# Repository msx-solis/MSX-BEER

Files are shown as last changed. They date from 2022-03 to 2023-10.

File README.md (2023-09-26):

# MSX-BEER
The MSX-Beer202 is a simple IDE interface for the MSX computers that not require to have more than 64K to use a hard disk. Original design by Solid and improved by some others (Yeti, FabF,...) in their own versions.

MSXmakers version 1.1 on "beer_ide_kicad" and "gerber" folders.
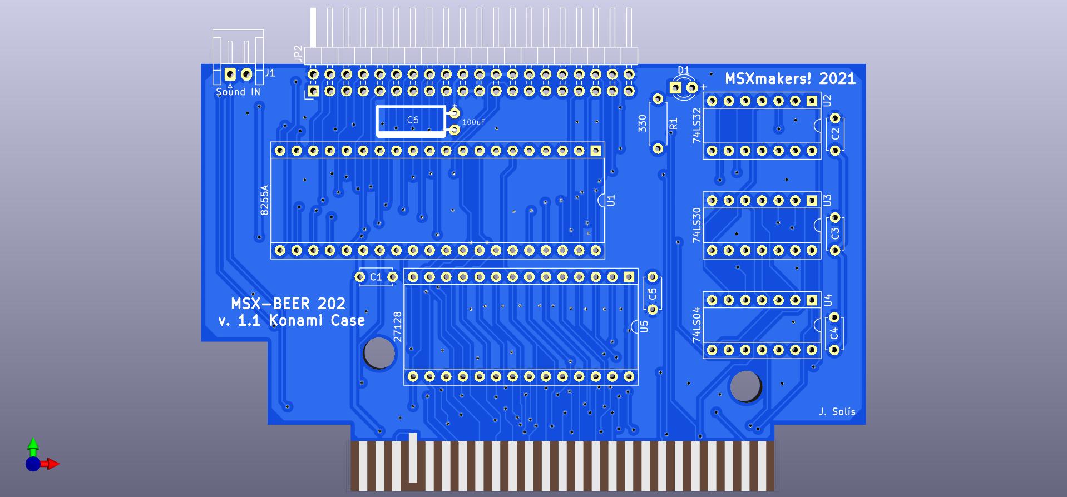
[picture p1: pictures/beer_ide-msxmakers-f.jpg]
card

More info:

Links for ide-beer202:

Here you have very good instructions (in portuguesse). Talk about the problems with some 82c55 versions and how to format with "SD fortater".
(Full overWrite y size adjustament = on).

http://basshp.blogspot.com/2014/04/beer-202-ata-ide-review.html

Here you have a demostration video for this distribution: https://www.youtube.com/watch?v=AeNEiQcKNEI&t=1s

And here you have lots of BEER interface details

https://www.pjrc.com/tech/8051/ide/wesley.html

Some more links

https://www.msx.org/wiki/Beer_202

https://hansotten.file-hunter.com/do-it-yourself/beer-ide/

https://www.pjrc.com/tech/8051/ide/wesley.html

https://www.msx.org/es/news/software/es/beer-202-ide-interface-utilidad-de-particionado

https://www.msx.org/forum/msx-talk/hardware/beer-202-ide-interface?page=2

http://www.retrocomputacion.com/forum/hardware_msx/4440/experimentos-con-la-beer-interface-ide-para-msx-1-y-2/&p=2

Some files:

https://msx.org/forum/msx-talk/hardware/beer-ide-bios-19rc1-source-code-wanted?page=1

https://sysadminmosaic.ru/en/msx/beer_ide/beer_ide

Discussion about the version SD and some more files:

http://www.nedopc.org/forum/viewtopic.php?f=96&t=18820&sid=d75385e94fd1d6dbab35a1f73d379176&start=45#p144050

Another software to clone RAW disks called HDD Raw Copy Rool v1.10 (for windows):

http://www.hddguru.com/

Another system menu for game loading.

https://www.msxall.com/download/msxmenu-v1.68-beer.zip

And here you have a demostration video for this ditribution: https://www.youtube.com/watch?v=a2agPfgZmI0&t=596s

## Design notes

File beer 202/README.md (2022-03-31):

BEER IDE 202 PACK

CONTENTS

SD FORMATER (UTILITY TO PREPARE THE OP CARD/ BE FORMATTED).
BEER IDE FORMATER (BEER FORMATTER FOR WINDOWS)
FIRMWARE 1.9 (FIRMWARE COMPATIBLE WITH COMPACT FLASH)
SCHEMATICS (ELECTRONIC SCHEME)

MORE INFORMATION:

http://www.basshp.msxall.com
http://www.basshp.blogspot.com

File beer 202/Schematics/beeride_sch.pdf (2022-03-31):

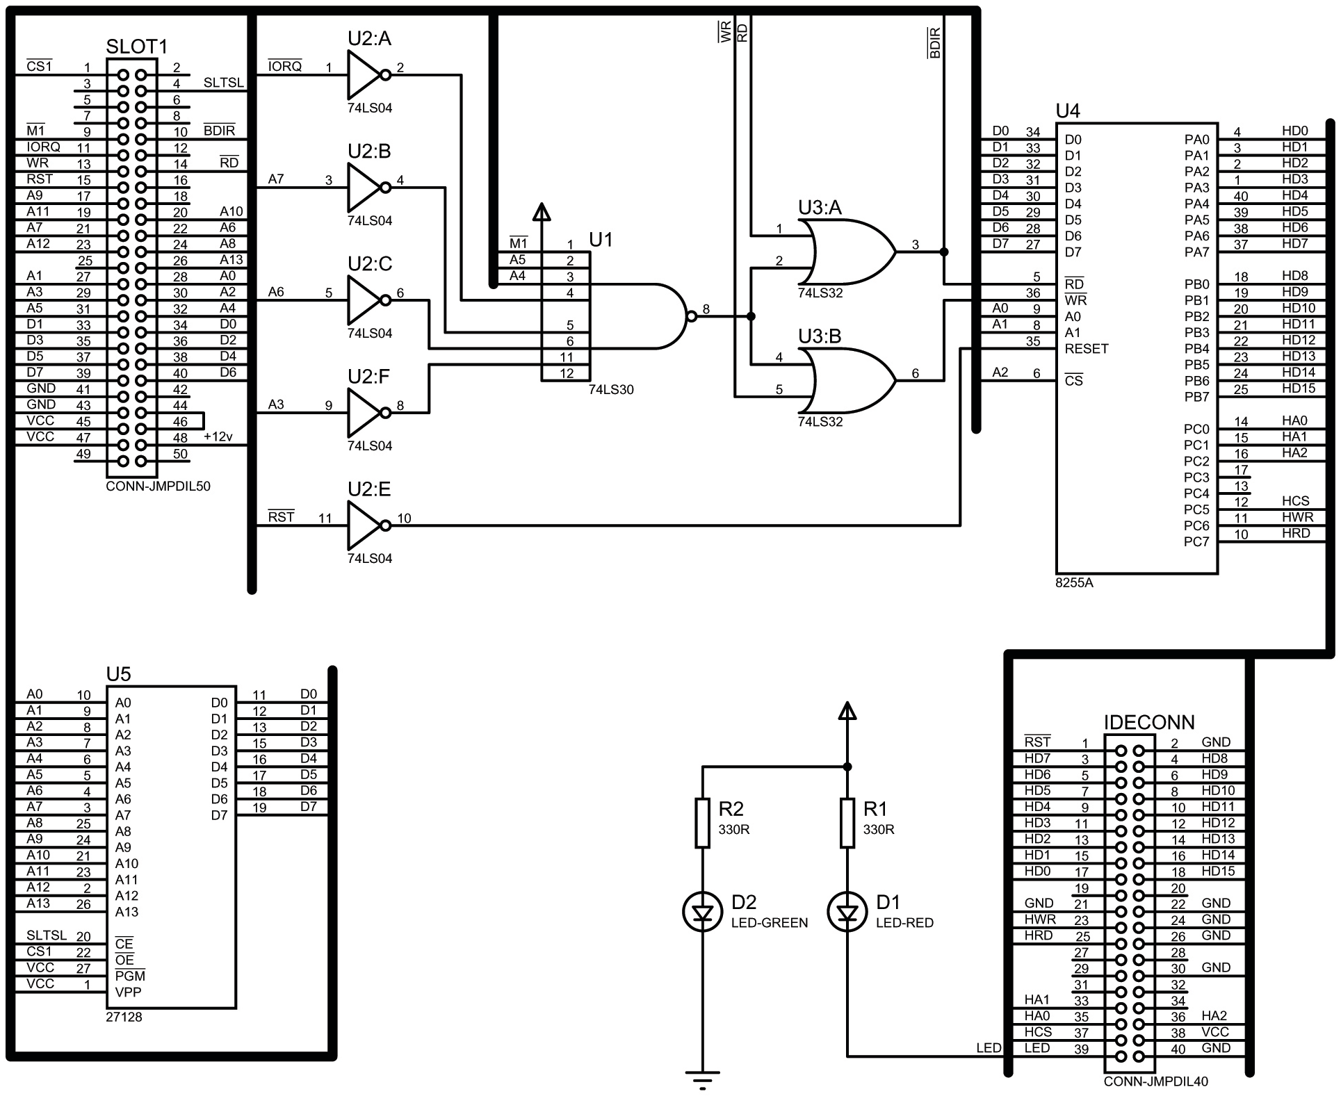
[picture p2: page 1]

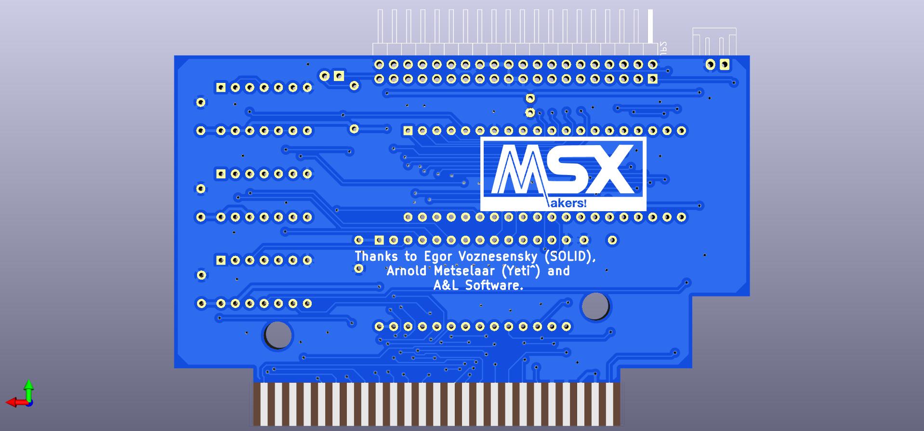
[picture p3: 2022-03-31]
pictures/beer_ide-msxmakers-b.jpg

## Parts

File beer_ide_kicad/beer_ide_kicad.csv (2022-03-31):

Reference | Value | Footprint | Datasheet
U4 | 74LS04 | Package_DIP:DIP-14_W7.62mm_Socket | http://www.ti.com/lit/gpn/sn74LS04
U3 | 74LS30 | Package_DIP:DIP-14_W7.62mm_Socket | http://www.ti.com/lit/gpn/sn74LS30
U2 | 74LS32 | Package_DIP:DIP-14_W7.62mm_Socket | http://www.ti.com/lit/gpn/sn74LS32
U1 | 8255A | Package_DIP:DIP-40_W15.24mm_Socket | http://aturing.umcs.maine.edu/~meadow/courses/cos335/Intel8255A.pdf
U5 | 27128 | Package_DIP:DIP-28_W15.24mm_Socket | http://eeshop.unl.edu/pdf/27128.pdf
JP2 | PINHD-02x20 | Connector_PinHeader_2.54mm:PinHeader_2x20_P2.54mm_Horizontal | ~
CN1 | MSX_SLOT_CON | MSXmakers2:CARTRIDGE_#_MSX_XL
D1 | LED | LED_THT:LED_D3.0mm | ~
C1 | 100nF | Capacitor_THT:C_Disc_D4.7mm_W2.5mm_P5.00mm | ~
C2 | 100nF | Capacitor_THT:C_Disc_D4.7mm_W2.5mm_P5.00mm | ~
C3 | 100nF | Capacitor_THT:C_Disc_D4.7mm_W2.5mm_P5.00mm | ~
C4 | 100nF | Capacitor_THT:C_Disc_D4.7mm_W2.5mm_P5.00mm | ~
C5 | 100nF | Capacitor_THT:C_Disc_D4.7mm_W2.5mm_P5.00mm | ~
C6 | 100uF | MSXmakers2:CP_tumbado | ~
J1 | Sound IN | Connector_JST:JST_EH_S2B-EH_1x02_P2.50mm_Horizontal | ~

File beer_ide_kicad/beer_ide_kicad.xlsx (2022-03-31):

Reference | Value | Footprint | Datasheet | QTY
C1-C5 | 100nF | C_Disc_D4.7mm_W2.5mm_P5.00mm | ~ | 5
C6 | Electrolithic cap 100uF / 16v | MSXmakers2:CP_tumbado | ~ | 1
PCB | MSX-BEER PCB | CARTRIDGE_#_MSX_XL |  | 1
D1 | LED 3mm | LED_D3.0mm | ~ | 1
J1 | 1x02 JST connector 90 degrees | JST_EH_S2B-EH_1x02_P2.50mm_Horizontal | ~ | 1
JP2 | PIN Header 02x20 shrouded | PinHeader_2x20_P2.54mm_Horizontal | ~ | 1
U1 | 82C55A | DIP-40_W15.24mm_Socket | http://aturing.umcs.maine.edu/~meadow/courses/cos335/Intel8255A.pdf | 1
U2 | 74LS32 | DIP-14_W7.62mm_Socket | http://www.ti.com/lit/gpn/sn74LS32 | 1
U3 | 74LS30 | DIP-14_W7.62mm_Socket | http://www.ti.com/lit/gpn/sn74LS30 | 1
U4 | 74LS04 | DIP-14_W7.62mm_Socket | http://www.ti.com/lit/gpn/sn74LS04 | 1
U5 | 27C128 | DIP-28_W15.24mm_Socket | http://eeshop.unl.edu/pdf/27128.pdf | 1
R1 | 330ohms | resistencia through hole |  | 1
Z1 | zócalo 40dip600 | 40DIP600 |  | 1
Z5 | zócalo 28dip600 | 28DIP600 |  | 1
Z2-4 | zócalo 14dip300 | 14DIP300 |  | 3

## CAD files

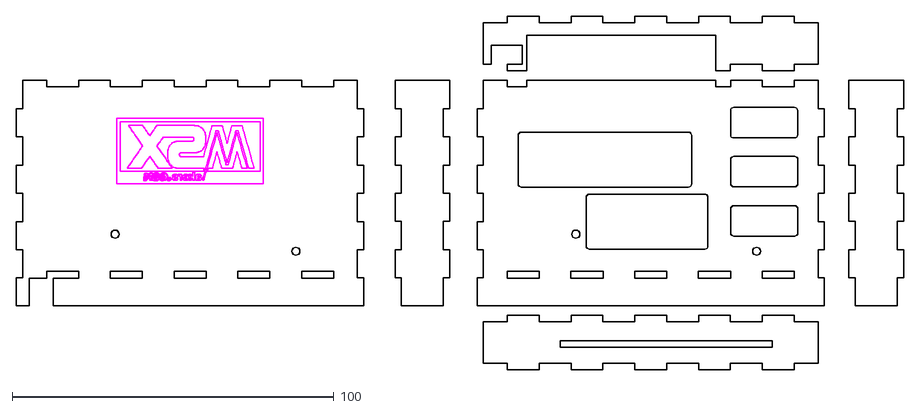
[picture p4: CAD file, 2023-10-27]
case/BEER_machimbrado_0.02mm_new_logo_R12.dxf
275.8 x 110.0

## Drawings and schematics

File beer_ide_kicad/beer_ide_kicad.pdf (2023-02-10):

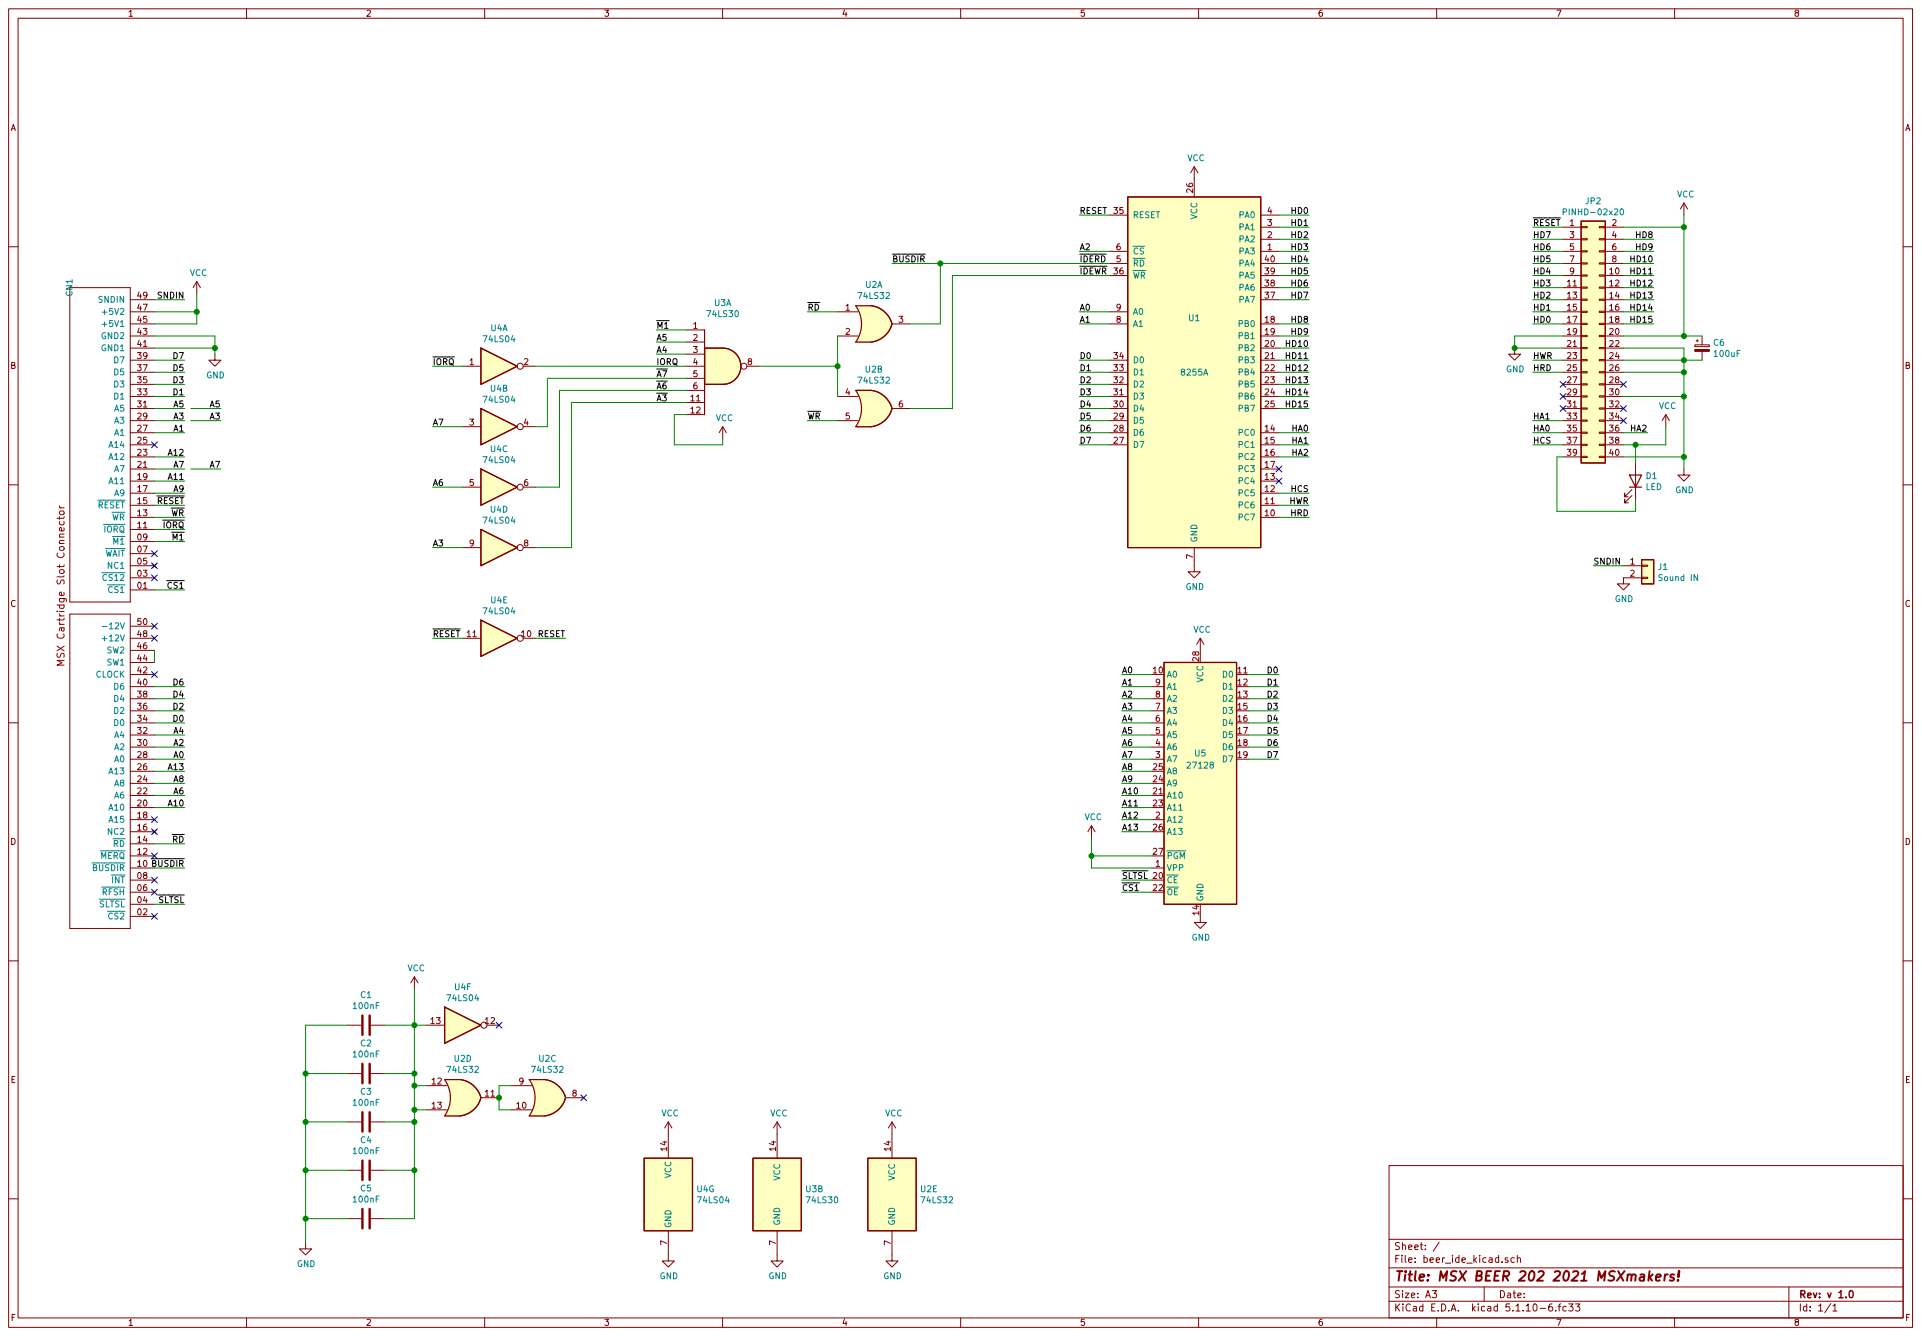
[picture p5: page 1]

File: beer_ide_kicad.sch Sheet: /
Id: 1/1 Title: MSX BEER 202 2021 MSXmakers!

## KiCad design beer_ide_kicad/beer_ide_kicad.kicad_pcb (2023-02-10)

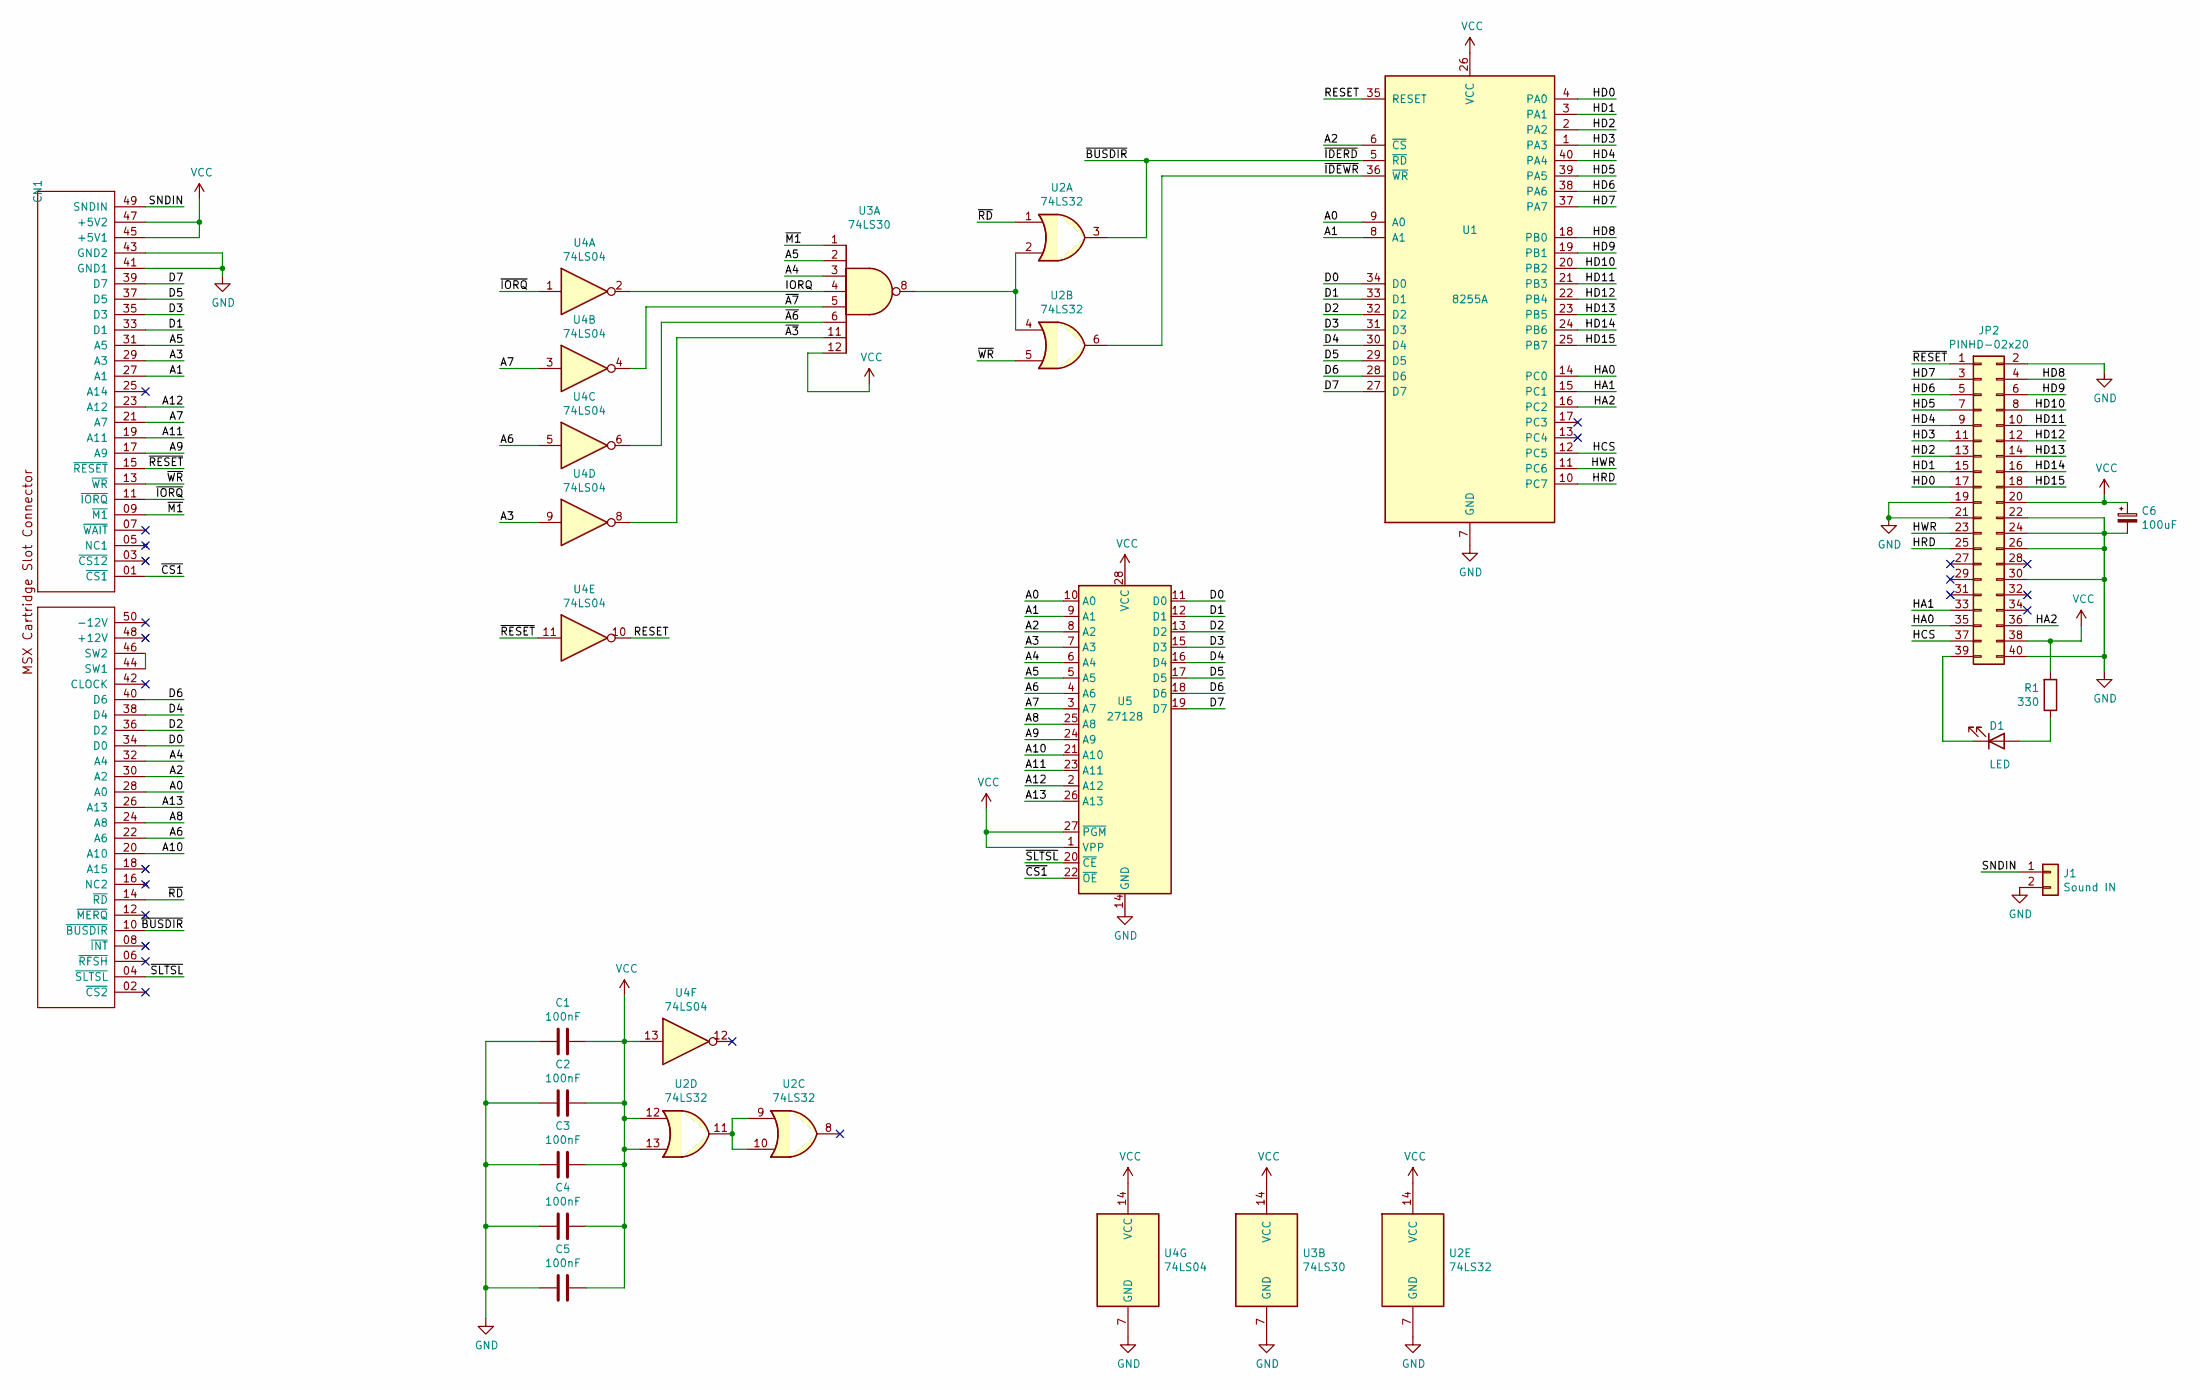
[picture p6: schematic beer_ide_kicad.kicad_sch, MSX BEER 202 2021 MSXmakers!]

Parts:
C1, C2, C3, C4, C5: 100nF; C_Disc_D4.7mm_W2.5mm_P5.00mm
C6: 100uF; CP_tumbado
CN1: MSX_SLOT_CON; CARTRIDGE_#_MSX_XL
D1: LED; LED_D3.0mm
J1: Sound IN; JST_EH_S2B-EH_1x02_P2.50mm_Horizontal
JP2: PINHD-02x20; PinHeader_2x20_P2.54mm_Horizontal
R1: 330; R_Axial_DIN0207_L6.3mm_D2.5mm_P7.62mm_Horizontal
U1: 8255A; DIP-40c_W15.24mm_LongPads
U2: 74LS32; DIP-14_W7.62mm_LongPads_0.9
U3: 74LS30; DIP-14c_W7.62mm_LongPads
U4: 74LS04; DIP-14c_W7.62mm_LongPads
U5: 27128; DIP-28c_W15.24mm_Socket_LongPads

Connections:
/A0: CN1.28 (A0), U1.9 (A0), U5.10 (A0)
/A1: CN1.27 (A1), U1.8 (A1), U5.9 (A1)
/A2: CN1.30 (A2), U1.6 (~CS), U5.8 (A2)
/A3: CN1.29 (A3), U4.9, U5.7 (A3)
/A4: CN1.32 (A4), U3.3, U5.6 (A4)
/A5: CN1.31 (A5), U3.2, U5.5 (A5)
/A6: CN1.22 (A6), U4.5, U5.4 (A6)
/A7: CN1.21 (A7), U4.3, U5.3 (A7)
/A8: CN1.24 (A8), U5.25 (A8)
/A9: CN1.17 (A9), U5.24 (A9)
/A10: CN1.20 (A10), U5.21 (A10)
/A11: CN1.19 (A11), U5.23 (A11)
/A12: CN1.23 (A12), U5.2 (A12)
/A13: CN1.26 (A13), U5.26 (A13)
/D0: CN1.34 (D0), U1.34 (D0), U5.11 (D0)
/D1: CN1.33 (D1), U1.33 (D1), U5.12 (D1)
/D2: CN1.36 (D2), U1.32 (D2), U5.13 (D2)
/D3: CN1.35 (D3), U1.31 (D3), U5.15 (D3)
/D4: CN1.38 (D4), U1.30 (D4), U5.16 (D4)
/D5: CN1.37 (D5), U1.29 (D5), U5.17 (D5)
/D6: CN1.40 (D6), U1.28 (D6), U5.18 (D6)
/D7: CN1.39 (D7), U1.27 (D7), U5.19 (D7)
/HA0: JP2.35, U1.14 (PC0)
/HA1: JP2.33, U1.15 (PC1)
/HA2: JP2.36, U1.16 (PC2)
/HCS: JP2.37, U1.12 (PC5)
/HD0: JP2.17, U1.4 (PA0)
/HD1: JP2.15, U1.3 (PA1)
/HD2: JP2.13, U1.2 (PA2)
/HD3: JP2.11, U1.1 (PA3)
/HD4: JP2.9, U1.40 (PA4)
/HD5: JP2.7, U1.39 (PA5)
/HD6: JP2.5, U1.38 (PA6)
/HD7: JP2.3, U1.37 (PA7)
/HD8: JP2.4, U1.18 (PB0)
/HD9: JP2.6, U1.19 (PB1)
/HD10: JP2.8, U1.20 (PB2)
/HD11: JP2.10, U1.21 (PB3)
/HD12: JP2.12, U1.22 (PB4)
/HD13: JP2.14, U1.23 (PB5)
/HD14: JP2.16, U1.24 (PB6)
/HD15: JP2.18, U1.25 (PB7)
/HRD: JP2.25, U1.10 (PC7)
/HWR: JP2.23, U1.11 (PC6)
/IORQ: U3.4, U4.2
/RESET: U1.35 (RESET), U4.10
/SNDIN: CN1.49 (SNDIN), J1.1
/~A3: U3.11, U4.8
/~A6: U3.6, U4.6
/~A7: U3.5, U4.4
/~BUSDIR: CN1.10 (~BUSDIR), U1.5 (~RD), U2.3
/~CS1: CN1.01 (~CS1), U5.22 (~OE)
/~IDEWR: U1.36 (~WR), U2.6
/~IORQ: CN1.11 (~IORQ), U4.1
/~M1: CN1.09 (~M1), U3.1
/~RD: CN1.14 (~RD), U2.1
/~RESET: CN1.15 (~RESET), JP2.1, U4.11
/~SLTSL: CN1.04 (~SLTSL), U5.20 (~CE)
/~WR: CN1.13 (~WR), U2.5
GND: C1.2, C2.2, C3.2, C4.2, C5.2, C6.2, CN1.41 (GND1), CN1.43 (GND2), J1.2, JP2.2, JP2.19, JP2.21, JP2.22, JP2.24, JP2.26, JP2.30, JP2.40, U1.7 (GND), U2.7 (GND), U3.7 (GND), U4.7 (GND), U5.14 (GND)
unnamed: CN1.44 (SW1), CN1.46 (SW2)
unnamed: D1.1 (K), JP2.39
unnamed: D1.2 (A), R1.1
unnamed: U2.2, U2.4, U3.8
unnamed: U2.9, U2.10, U2.11
VCC: C1.1, C2.1, C3.1, C4.1, C5.1, C6.1, CN1.45 (+5V1), CN1.47 (+5V2), JP2.20, JP2.38, R1.2, U1.26 (VCC), U2.12, U2.13, U2.14 (VCC), U3.12, U3.14 (VCC), U4.13, U4.14 (VCC), U5.1 (VPP), U5.27 (~PGM), U5.28 (VCC)

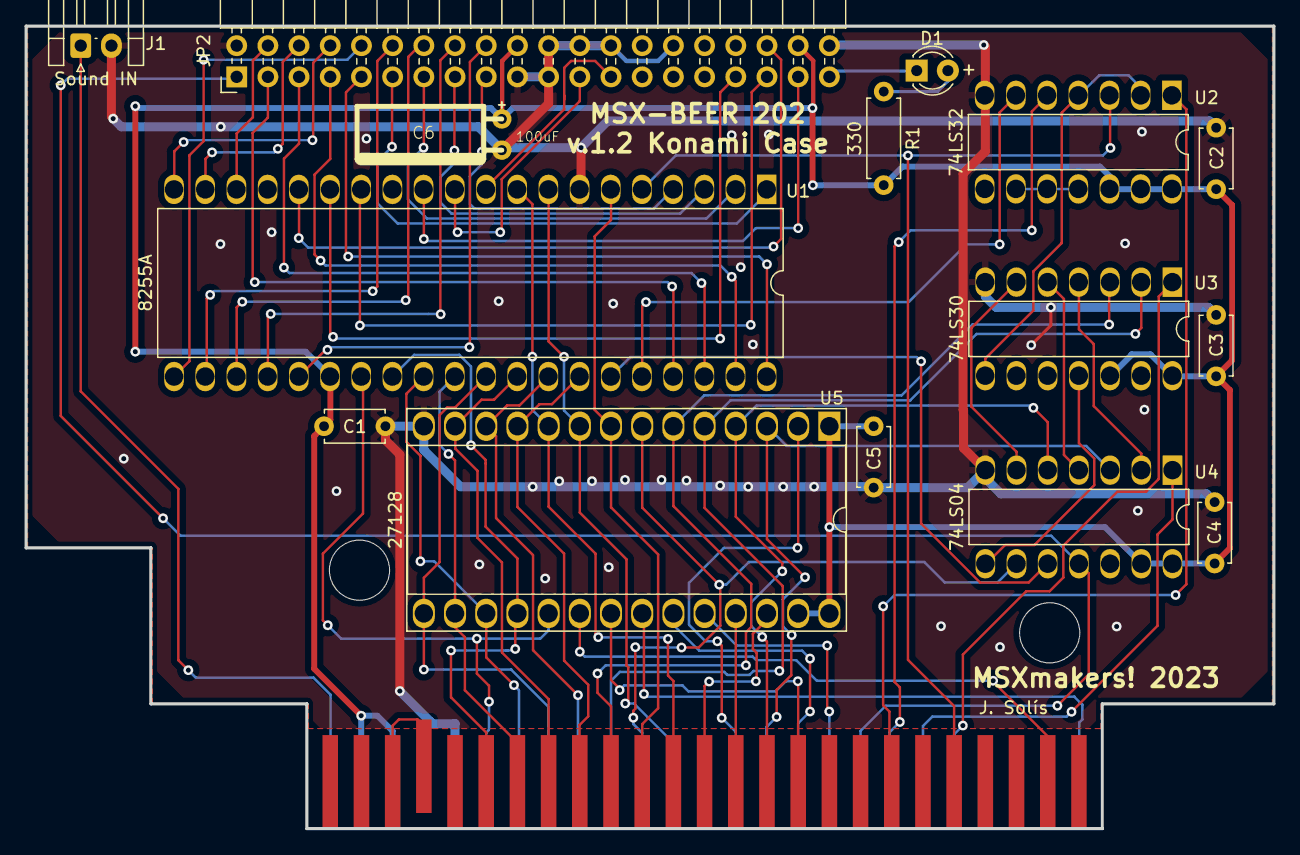
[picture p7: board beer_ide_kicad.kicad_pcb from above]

Board: 2 copper layers, 101.6 x 65.3 mm, 16 parts (0 on the bottom side), 66 nets.
